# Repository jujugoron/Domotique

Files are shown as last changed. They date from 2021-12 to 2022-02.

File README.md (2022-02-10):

# Domotique
Projet de box domotique (projet en cours de réalisation)

# Objectifs:
*Ce projet a pour but de mettre en oeuvre un reseau de communication Zigbee pour créer une box domotique. 
Les composants utilisés sont les suivants:

[Raspberry PI 3B](https://fr.rs-online.com/web/p/raspberry-pi/1828032/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)

[Ecran tactile](https://fr.rs-online.com/web/p/ecrans-raspberry-pi/8997466/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)

[Antenne Zigbee](https://phoscon.de/en/raspbee2/)

[Capteur de temperature]( https://expo.tuya.com/product/712038)

[Prise connectée]( https://www.batna24.com/en/p/xiaomi-mi-smart-plug-zigbee-wall-plug-rmmmh#support)

## Hardware
Installation de l'ecran et de la RPI 
installation du capteur Zigbee
### Electronique
relier l'ecran et l'antenne Raspbee sur la Raspberry PI. (utiliser la carte kicad si besoin)

### Support
un modèle fusion 360 est disponible dans le dossier Hardware. Il est inspiré du modèle [thingiverse]( https://www.thingiverse.com/thing:2756684 )

le modèle a été imprimé en PLA et TPU avec une Creality CR10

## Software
###installer Raspbian sur la RPI

### Mettre à jour

```
sudo apt update
sudo apt upgrade
```

### Installation de deCONZ et de la puce RaspBee

#### Désactivation de la console Serie 

```
sudo raspi-config
```
Advanced Options -> Serial -> Disable Commandline over Serial

#### Désactivation du service getty
```
sudo systemctl disable serial-getty@ttyAMA0.service
```
#### Désactivation du bluetooth 

1. Ajouter la ligne suivant dans le fichier /boot/config.txt:
```
sudo nano /boot/config.txt
```
```
dtoverlay=pi3-disable-bt
```
2. Désactivation du modem Bluetooth
```
sudo systemctl disable hciuart
```
#### Installation de l'application DeCONZ
```
sudo gpasswd -a $USER dialout
wget -O - http://phoscon.de/apt/deconz.pub.key | sudo apt-key add -
sudo sh -c "echo 'deb http://phoscon.de/apt/deconz $(lsb_release -cs) main' > /etc/apt/sources.list.d/deconz.list"
sudo apt update
sudo apt install deconz
sudo systemctl edit deconz-gui
```

ajouter l'option

```
–ws-port=8081
```

#### Lancement de l'application
```
sudo systemctl disable deconz
sudo systemctl stop deconz
sudo systemctl enable deconz-gui
```

#### Redémarrage
```
sudo reboot
```

[Tuto]( https://presentationdeconz.wordpress.com/installation/)

### Installation d'Apache2
```
sudo apt install apache2 -y
```
```
sudo chown -R pi:www-data /var/www/html/
sudo chmod -R 770 /var/www/html/
```

###Installation de PHP

```
sudo apt install php -y

sudo service apache2 restart

```

### placer les fichiers de l'application Web "Software" dans le dossier /var/www/html 

```
sudo cp -r /home/pi/Desktop/Software /var/www/html
```

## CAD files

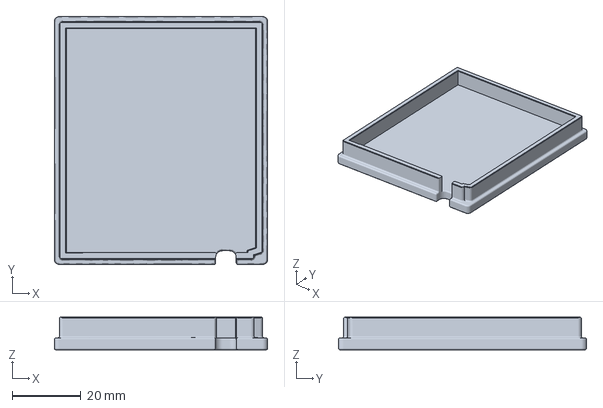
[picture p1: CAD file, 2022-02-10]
Hardware/Case/couvercle.3mf
62.0 x 72.1 x 9.50 mm

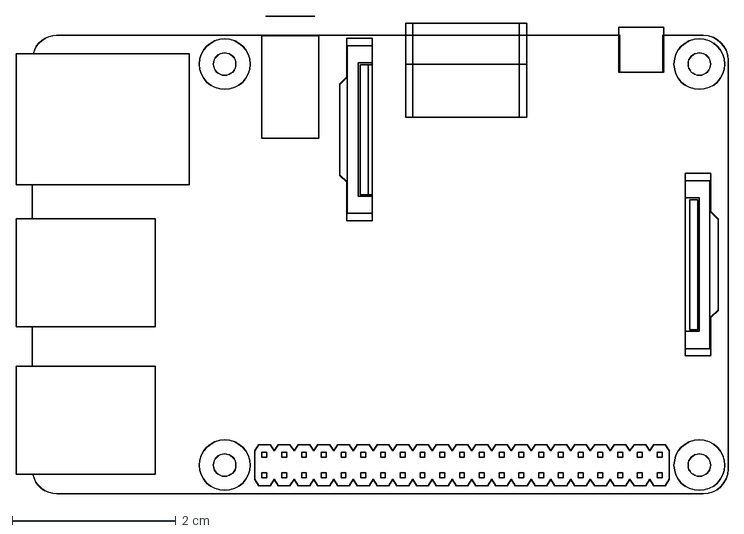
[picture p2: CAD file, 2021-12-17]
Hardware/Electronics/carte_domotique/rpi.dxf
8.70 x 5.83 cm

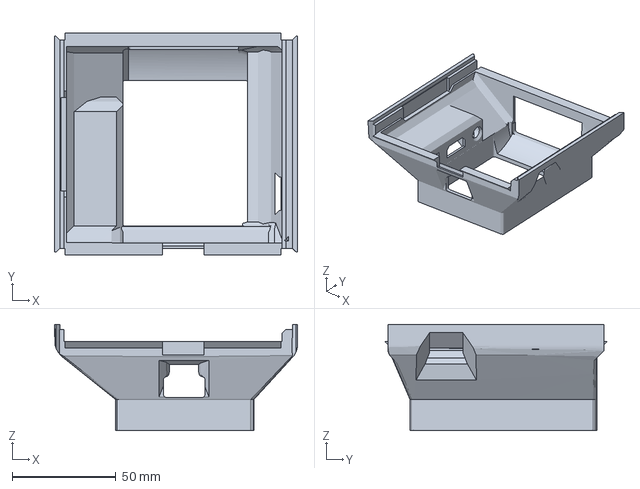
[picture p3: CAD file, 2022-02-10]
Hardware/Case/milieu.3mf
117.0 x 107.1 x 51.2 mm

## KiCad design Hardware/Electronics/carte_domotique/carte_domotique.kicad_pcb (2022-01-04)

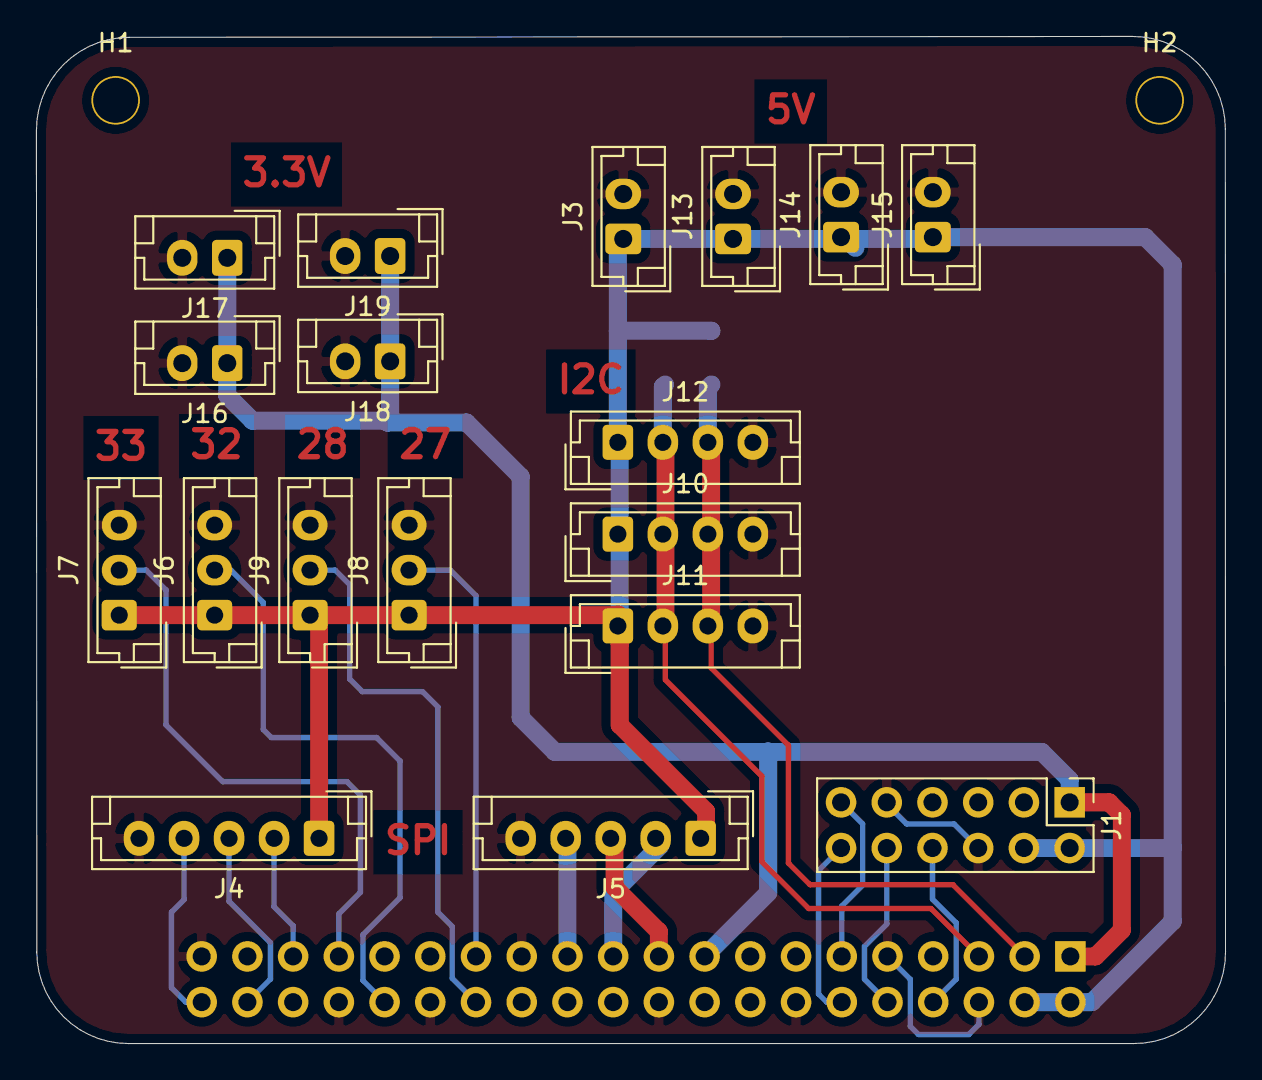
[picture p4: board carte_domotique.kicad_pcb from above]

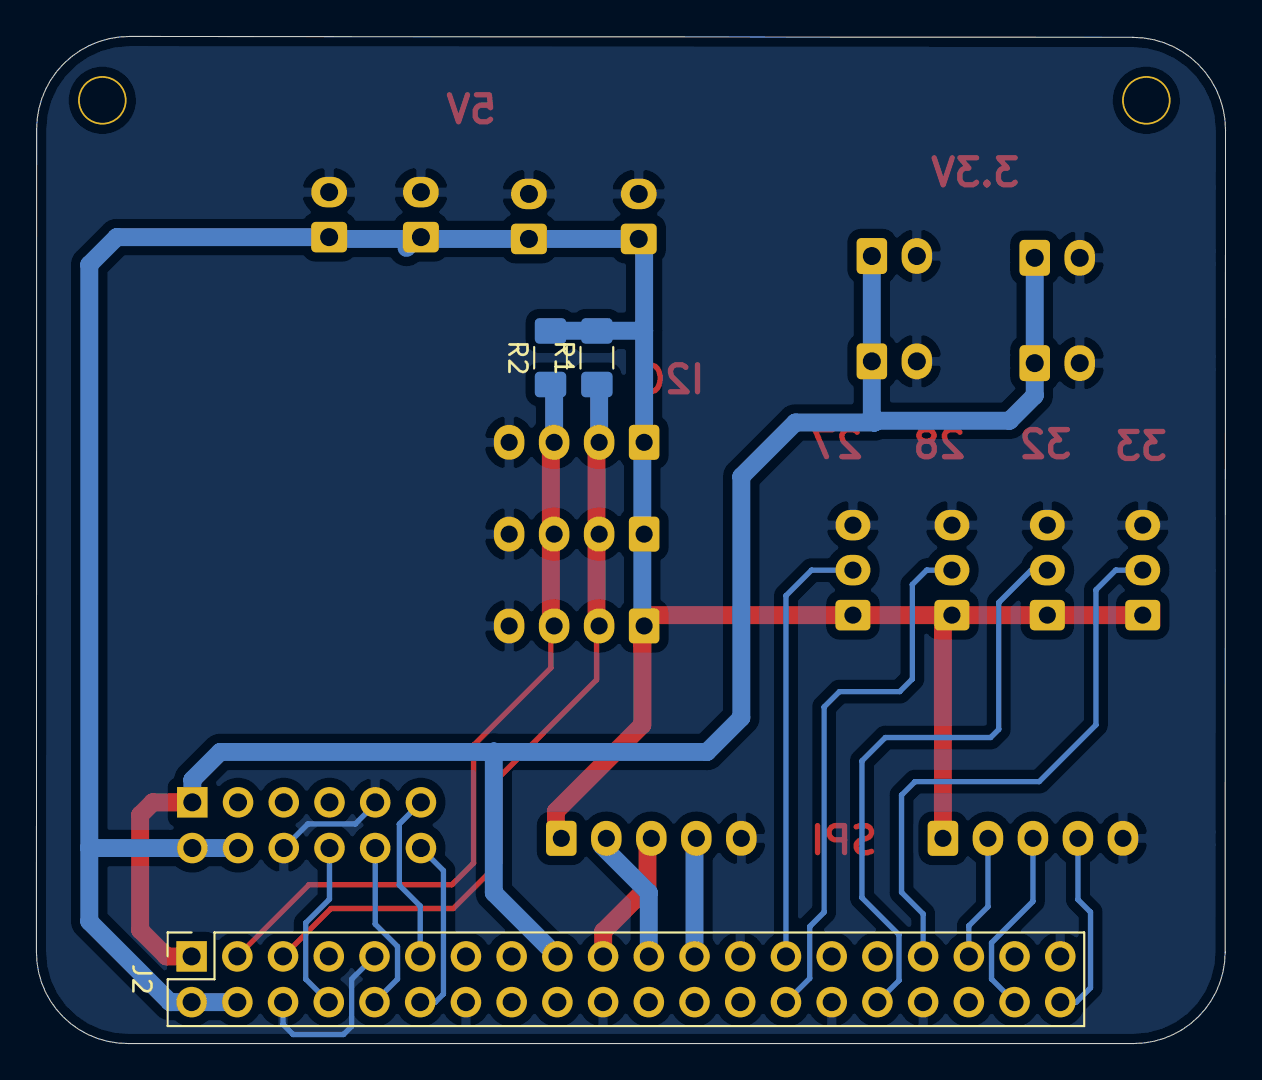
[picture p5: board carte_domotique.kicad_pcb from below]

Board: 2 copper layers, 66.1 x 55.9 mm, 23 parts (3 on the bottom side), 19 nets.

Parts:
H1, H2: MountingHole_Pad; MountingHole_2.2mm_M2
J1: Conn_02x06_Odd_Even; PinHeader_2x06_P2.54mm_Vertical
J2: Raspberry_Pi_2_3; PinSocket_2x20_P2.54mm_Vertical
J3, J13, J14, J15, J16, J17, J18, J19: Conn_01x02; JST_EH_B2B-EH-A_1x02_P2.50mm_Vertical
J4, J5: Conn_01x05; JST_EH_B5B-EH-A_1x05_P2.50mm_Vertical
J6, J7, J8, J9: Conn_01x03; JST_EH_B3B-EH-A_1x03_P2.50mm_Vertical
J10, J11, J12: Conn_01x04; JST_EH_B4B-EH-A_1x04_P2.50mm_Vertical
R1, R2: R; R_1206_3216Metric_Pad1.42x1.75mm_HandSolder

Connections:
+3V3: J1.1, J2.1, J2.17, J16.1, J17.1, J18.1, J19.1
+5V: J1.2, J1.4, J2.2, J2.4, J3.1, J4.1, J5.1, J6.1, J7.1, J8.1, J9.1, J10.1, J11.1, J12.1, J13.1, J14.1, J15.1, R1.2, R2.2
/SW1: J1.12, J2.12
GND: J1.6, J1.9, J2.6, J2.9, J2.14, J2.20, J2.25, J2.30, J2.34, J2.39, J3.2, J4.5, J5.5, J6.3, J7.3, J8.3, J9.3, J10.4, J11.4, J12.4, J13.2, J14.2, J15.2, J16.2, J17.2, J18.2, J19.2
unnamed: J1.8, J2.8
unnamed: J1.10, J2.10
unnamed: J2.19, J5.3
unnamed: J2.21, J5.2
unnamed: J2.23, J5.4
unnamed: J2.27, J8.2
unnamed: J2.28, J9.2
unnamed: J2.32, J6.2
unnamed: J2.33, J7.2
unnamed: J2.35, J4.2
unnamed: J2.38, J4.3
unnamed: J2.40, J4.4
SCL: J2.5, J10.2, J11.2, J12.2, R1.1
SDA: J2.3, J10.3, J11.3, J12.3, R2.1
reset: J1.11, J2.11

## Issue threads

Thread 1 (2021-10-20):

**Automation**

jujugoron, 2021-10-20:
[Automatically move your cards](https://docs.github.com/articles/configuring-automation-for-project-boards/) to the right place based on the status and activity of your issues and pull requests.

Closed 2021-10-20.

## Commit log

2021-10-20 creation fichier kicad carte
    [carte_domotique.kicad_pcb, carte_domotique.sch]
2021-11-02 debut de la carte electronique
    [carte_domotique.kicad_pcb, carte_domotique.sch]
2021-11-02 update readme
    test avec les ```
2021-11-02 Update README.md
    création du cadre de code
2021-11-04 motification du conneteur pour le raspbee II
    [carte_domotique.kicad_pcb, carte_domotique.sch]
2021-11-04 kicad+ doc
    ajout de document
    modification avec le cablage de l'antenne xbee d'après la datasheet
    [carte_domotique.sch]
2021-11-04 kicad
    schematic + empreinte
    tracage des bus
    + mise en place des connecteur spi i2c pwm pcm 5v 33v gnd
    [carte_domotique.kicad_pcb, carte_domotique.sch, file618EA7DC.sch]
2021-11-05 Update README.md
    ajout du tuto d'installation de Deconz
2021-12-17 carte 1
    carte proto 1
    [carte_domotique.kicad_pcb, carte_domotique.sch, rpi.dxf]
2022-01-04 carte electronique
    finalisation de la carte électronique
    + exportation 3D
    [carte_domotique-B_Cu.gbr, carte_domotique-Edge_Cuts.gbr, carte_domotique-F_Cu.gbr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]
2022-01-04 conception3D
    ajout de l'assemblage de base
2022-01-31 Update README.md
    ajout installation Apache2 + PHP+ para de deconz
